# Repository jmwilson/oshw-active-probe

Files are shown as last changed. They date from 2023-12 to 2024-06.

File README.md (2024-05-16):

# Active probe project

Read about this project at https://jmw.name/projects/active-probe/

## Repository structure

* `board`: schematic and layout design files
	- `Mfg`: Gerbers and manufacturing outputs
* `measurement`: prototype performance measurements
* `simulation\openems`: openEMS simulation files
	- `probe`: input network simulation
	- `transmission-lines`: coplanar waveguide transmission line simulation
* `simulation\spice`: circuit simulations

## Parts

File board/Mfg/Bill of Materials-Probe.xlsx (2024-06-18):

Comment | Description | Designator | Footprint | LibRef | Quantity | Manufacturer | Manufacturer Part Number | Manufacturer 1 | Manufacturer 2 | Manufacturer 3 | Manufacturer 4 | Manufacturer Part Number 1 | Manufacturer Part Number 2 | Manufacturer Part Number 3 | Manufacturer Part Number 4 | Supplier Part Number 1
4.70K | RES 4.70K OHM 1% 1/10W 0603 | R24 | RESC0603(1608)_M | RESC0603-4K70-1pct | 1 | Yageo | RC0603FR-074K7L | Yageo | Stackpole Electronics | Vishay Dale | Panasonic Electronic Components | RC0603FR-074K7L | RMCF0603FT4K70 | CRCW06034K70FKEA | ERJ-3EKF4701V
422K | RES 422K OHM 1% 1/16W 0402 | R4 | RESC0402(1005)_M | RESC0402-422K-1pct | 1 | Yageo | RC0402FR-07422KL | Yageo | Stackpole Electronics | Vishay Dale | Panasonic Electronic Components | RC0402FR-07422KL | RMCF0402FT422K | CRCW0402422KFKED | ERJ-2RKF4223X
100 | RES 100 OHM 1% 1/16W 0402 | R1 | RESC0402(1005)_M | RESC0402-100R-1pct | 1 | Yageo | RC0402FR-07100RL | Yageo | Stackpole Electronics | Vishay Dale | Panasonic Electronic Components | RC0402FR-07100RL | RMCF0402FT100R | CRCW0402100RFKED | ERJ-2RKF1000X
91.0K | RES 91.0K OHM 1% 1/16W 0402 | R21 | RESC0402(1005)_M | RESC0402-91K0-1pct | 1 | Yageo | RC0402FR-0791KL | Yageo | Stackpole Electronics | Vishay Dale | Panasonic Electronic Components | RC0402FR-0791KL | RMCF0402FT91K0 | CRCW040291K0FKED | ERJ-2RKF9102X
68 | RES 68 OHM 1% 1/16W 0402 | R9 | RESC0402(1005)_M | RESC0402-68R0-1pct | 1 | Yageo | RC0402FR-0768RL | Yageo | Stackpole Electronics | Vishay Dale | Panasonic Electronic Components | RC0402FR-0768RL | RMCF0402FT68R0 | CRCW040268R0FKED | ERJ-2RKF68R0X
66.5K | RES 66.5K OHM 1% 1/16W 0402 | R8 | RESC0402(1005)_M | RESC0402-66K5-1pct | 1 | Yageo | RC0402FR-0766K5L | Yageo | Stackpole Electronics | Vishay Dale | Panasonic Electronic Components | RC0402FR-0766K5L | RMCF0402FT66K5 | CRCW040266K5FKED | ERJ-2RKF6652X
51.0K | RES 51.0K OHM 1% 1/16W 0402 | R11 | RESC0402(1005)_M | RESC0402-51K0-1pct | 1 | Yageo | RC0402FR-0751KL | Yageo | Stackpole Electronics | Vishay Dale | Panasonic Electronic Components | RC0402FR-0751KL | RMCF0402FT51K0 | CRCW040251K0FKED | ERJ-2RKF5102X
49.9 | RES 49.9 OHM 1% 1/16W 0402 | R19 | RESC0402(1005)_M | RESC0402-49R9-1pct | 1 | Yageo | RC0402FR-0749R9L | Yageo | Stackpole Electronics | Vishay Dale | Panasonic Electronic Components | RC0402FR-0749R9L | RMCF0402FT49R9 | CRCW040249R9FKED | ERJ-2RKF49R9X
41.2K | RES 41.2K OHM 1% 1/16W 0402 | R20 | RESC0402(1005)_M | RESC0402-41K2-1pct | 1 | Yageo | RC0402FR-0741K2L | Yageo | Stackpole Electronics | Vishay Dale | Panasonic Electronic Components | RC0402FR-0741K2L | RMCF0402FT41K2 | CRCW040241K2FKED | ERJ-2RKF4122X
18.0K | RES 18.0K OHM 1% 1/16W 0402 | R23 | RESC0402(1005)_M | RESC0402-18K0-1pct | 1 | Yageo | RC0402FR-0718KL | Yageo | Stackpole Electronics | Vishay Dale | Panasonic Electronic Components | RC0402FR-0718KL | RMCF0402FT18K0 | CRCW040218K0FKED | ERJ-2RKF1802X
17.8K | RES 17.8K OHM 1% 1/16W 0402 | R16 | RESC0402(1005)_M | RESC0402-17K8-1pct | 1 | Yageo | RC0402FR-0717K8L | Yageo | Stackpole Electronics | Vishay Dale | Panasonic Electronic Components | RC0402FR-0717K8L | RMCF0402FT17K8 | CRCW040217K8FKED | ERJ-2RKF1782X
10.0M | RES 10.0M OHM 1% 1/16W 0402 | R10 | RESC0402(1005)_M | RESC0402-10M0-1pct | 1 | Yageo | RC0402FR-0710ML | Yageo | Stackpole Electronics | Vishay Dale | Panasonic Electronic Components | RC0402FR-0710ML | RMCF0402FT10M0 | CRCW040210M0FKED
10.0K | RES 10.0K OHM 1% 1/16W 0402 | R12 | RESC0402(1005)_M | RESC0402-10K0-1pct | 1 | Yageo | RC0402FR-0710KL | Yageo | Stackpole Electronics | Vishay Dale | Panasonic Electronic Components | RC0402FR-0710KL | RMCF0402FT10K0 | CRCW040210K0FKED | ERJ-2RKF1002X
10.2K | RES 10.2K OHM 1% 1/16W 0402 | R22 | RESC0402(1005)_M | RESC0402-10K2-1pct | 1 | Yageo | RC0402FR-0710K2L | Yageo | Stackpole Electronics | Vishay Dale | Panasonic Electronic Components | RC0402FR-0710K2L | RMCF0402FT10K2 | CRCW040210K2FKED | ERJ-2RKF1022X
5.60K | RES 5.60K OHM 1% 1/16W 0402 | R15 | RESC0402(1005)_M | RESC0402-5K60-1pct | 1 | Yageo | RC0402FR-075K6L | Yageo | Stackpole Electronics | Vishay Dale | Panasonic Electronic Components | RC0402FR-075K6L | RMCF0402FT5K60 | CRCW04025K60FKED | ERJ-2RKF5601X
0 | RES 0 OHM JUMPER 0402 | R2 | RESC0402(1005)_M | R0402-0R0-JMP | 1 | Yageo | RC0402FR-071RL | Yageo | Stackpole Electronics | Vishay Dale | Panasonic Electronic Components | RC0402FR-071RL | RMCF0402FT1R00 | CRCW04021R00FNED | ERJ-2GE0R00X
1.91M | RES 1.91M OHM 1% 1/16W 0402 | R6 | RESC0402(1005)_M | RESC0402-1M91-1pct | 1 | Yageo | RC0402FR-071M91L | Yageo | Stackpole Electronics | Vishay Dale | Panasonic Electronic Components | RC0402FR-071M91L | RMCF0402FT1M91 | CRCW04021M91FKED
1.60M | RES 1.60M OHM 1% 1/16W 0402 | R3 | RESC0402(1005)_M | RESC0402-1M60-1pct | 1 | Yageo | RC0402FR-071M6L | Yageo | Stackpole Electronics | Vishay Dale | Panasonic Electronic Components | RC0402FR-071M6L | RMCF0402FT1M60 | CRCW04021M60FKED
1.00K | RES 1.00K OHM 1% 1/16W 0402 | R17, R18 | RESC0402(1005)_M | RESC0402-1K00-1pct | 2 | Yageo | RC0402FR-071KL | Yageo | Stackpole Electronics | Vishay Dale | Panasonic Electronic Components | RC0402FR-071KL | RMCF0402FT1K00 | CRCW04021K00FKED | ERJ-2RKF1001X
1k | TRIMMER 1K OHM 0.25W J LEAD TOP | R13 | PVG3A | PVG3A102C01R00 | 1 | Bourns | PVG3A102C01R00 |  |  |  |  |  |  |  |  | 490-2643-6-ND
1u | Cap Ceramic 1uF 50V X7R 10% SMD 0805 125C Blister T/R | C7 | CAPC0805(2012)145_M | CC0805KKX7R9BB105 | 1 | Yageo | CC0805KKX7R9BB105 |  |  |  |  |  |  |  |  | 311-1886-1-ND
1.1p | CAP CER 1.1PF±0.05PF 50V C0G/NP0 0402 | C4 | CAPC0402(1005)50_M | GJM1555C1H1R1WB01 | 1 | Murata | GJM1555C1H1R1WB01D
1.3p | CAP CER 1.3PF±0.05PF 50V C0G/NP0 0402 | C5 | CAPC0402(1005)50_M | GJM1555C1H1R3WB01 | 1 | Murata | GJM1555C1H1R3WB01D
2.1/5.5mm | CONN PWR JACK 2X5.5MM SOLDER | J4 | CUI PJ-002A | PJ-002A | 1 | CUI | PJ-002A |  |  |  |  |  |  |  |  | CP-002A-ND
4.7u | CAP CER 4.7UF 50V X7R 0805 | C22, C23, C24, C25 | CAPC0805(2012)100_M | GRM21BZ71H475KE15K | 4 | Murata | GRM21BZ71H475KE15K |  |  |  |  |  |  |  |  | 490-GRM21BZ71H475KE15KCT-ND
10n | CAP CER 10NF±5% 25V C0G 0402, CAP CER 10NF±10% 50V X7R 0402 | C6, C8, C9, C18, C19, C20, C21 | CAPC0402(1005)50_M | GRM1555C1E103JE01, GRM155R71H103KA88 | 7 | Murata | GRM1555C1E103JE01D, GRM155R71H103KA88D
22u | CAP TANT 22UF 10% 16V 1411 | C10, C11 | KEMET B_M | T491B226K016AT | 2 | KEMET | T491B226K016AT |  |  |  |  |  |  |  |  | 399-8312-6-ND
47p | CAP CER 47PF±5% 50V C0G 0402 | C2 | CAPC0402(1005)50_M | CL05C470JB5NNN | 1 | Samsung Electro-Mechanics | CL05C470JB5NNNC
100n | CAPACITOR CERAMIC, 0.1UF, 50V, X7R, 10%, 0603 | C12, C13 | CAPC0603(1608)100_M | CC0603KRX7R9BB104 | 2 | Yageo | CC0603KRX7R9BB104 |  |  |  |  |  |  |  |  | 311-1344-1-ND
100n LICC | CAP CER 0.1UF 25V X7R 0306 | C14, C15, C16, C17 | CAPC0306_M | TWK107B7104MVHT | 4 | Taiyo Yuden | TWK107B7104MVHT |  |  |  |  |  |  |  |  | 587-6181-1-ND
100p | CAP CER 100PF±5% 50V C0G 0402 | C3 | CAPC0402(1005)50_M | CL05C101JB5NNN | 1 | Samsung Electro-Mechanics | CL05C101JB5NNNC
330p | CAP CER 330PF±5% 50V C0G 0402 | C1 | CAPC0402(1005)50_M | GRM1555C1H331JA01 | 1 | Murata | GRM1555C1H331JA01D
0339-0-15-01-15-27-10-0 | CONN PIN RCPT | J1, J2, J5 | MILL-MAX 0339 | 0339-0-15-01-15-27-10-0 | 3 | Mill-Max | 0339-0-15-01-15-27-10-0 |  |  |  |  |  |  |  |  | 0339-0-15-01-15-27-10-0-ND
901-10511-3 | CONN SMA JACK STR 50OHM EDGE MNT | J3 | 901-10511-3 | 901-10511-3 | 1 | Amphenol RF | 901-10511-3 |  |  |  |  |  |  |  |  | ARF2500-ND
BAT54 | DIODE SCHOTTKY 30V 200MA TO236AB | D1 | INF-PG-SC59_M | BAT54 | 1 | Nexperia USA | BAT54,215 |  |  |  |  |  |  |  |  | 1727-2900-6-ND
BUF802 | WIDE-BANDWIDTH JFET BUFFER | U1 | VQFN16_RGT_TEX- OSHPARK | BUF802IRGTR | 1 | Texas Instruments | BUF802IRGTR |  |  |  |  |  |  |  |  | 296-BUF802IRGTRCT-ND
LTC3261 | IC REG CHARG PUMP INV 12MSOP | U4 | MSOP-12_MSE | LTC3261EMSE | 1 | Analog Devices / Linear Technology | LTC3261EMSE#TRPBF |  |  |  |  |  |  |  |  | LTC3261EMSE#TRPBFCT-ND
OPA140 | IC OPAMP JFET 1 CIRCUIT 8SOIC | U2 | SOIC-8 | OPA140AIDR | 1 | Texas Instruments | OPA140AIDR |  |  |  |  |  |  |  |  | 296-43606-6-ND
TPS7A39 | IC REG LINEAR POS/NEG ADJ 10WSON | U3 | DSC0010J_NV | TPS7A3901DSCR | 1 | Texas Instruments | TPS7A3901DSCR |  |  |  |  |  |  |  |  | 296-TPS7A3901DSCRCT-ND
VLMTG1300-GS08 | LED GREEN 0603 SMD | D2 | LED0603(1608)_M | VLMTG1300-GS08 | 1 | Vishay Semiconductors | VLMTG1300-GS08 |  |  |  |  |  |  |  |  | VLMTG1300-GS08CT-ND

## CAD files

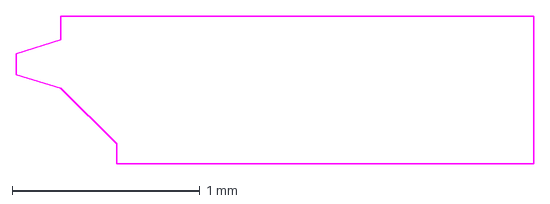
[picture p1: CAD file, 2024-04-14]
board/Probe-outline.DXF
2.76 x 0.787 mm

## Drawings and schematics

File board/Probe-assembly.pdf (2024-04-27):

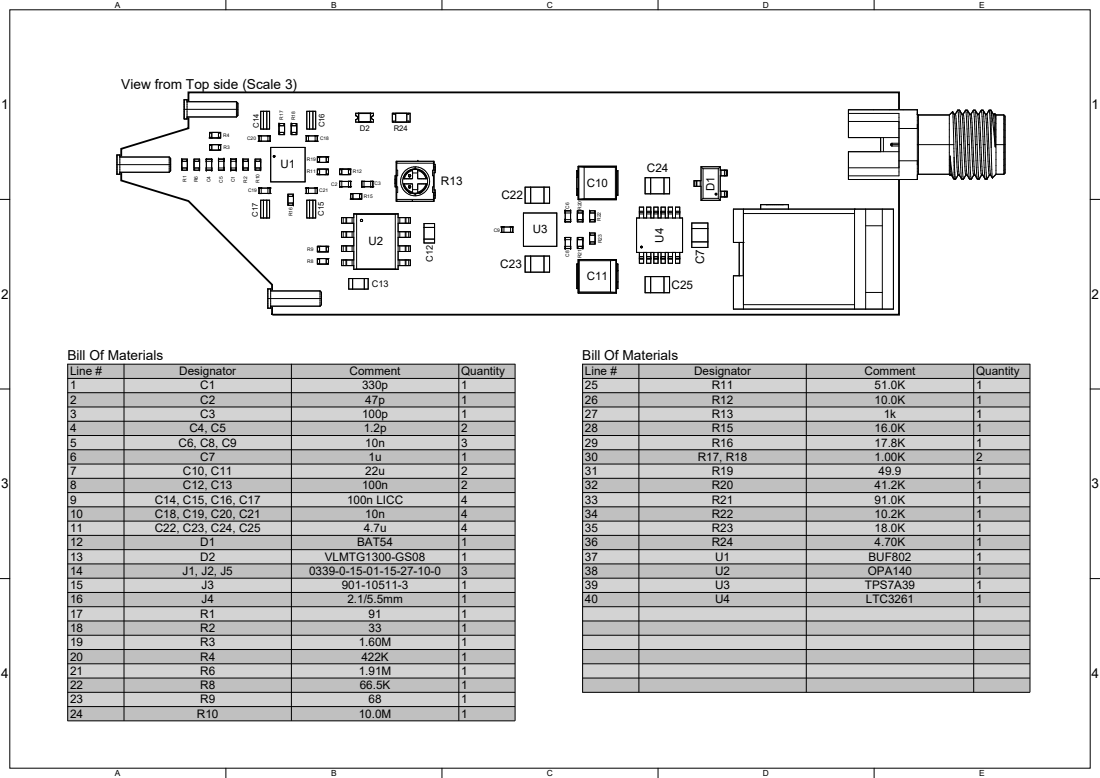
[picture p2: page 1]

View from Top side (Scale 3)

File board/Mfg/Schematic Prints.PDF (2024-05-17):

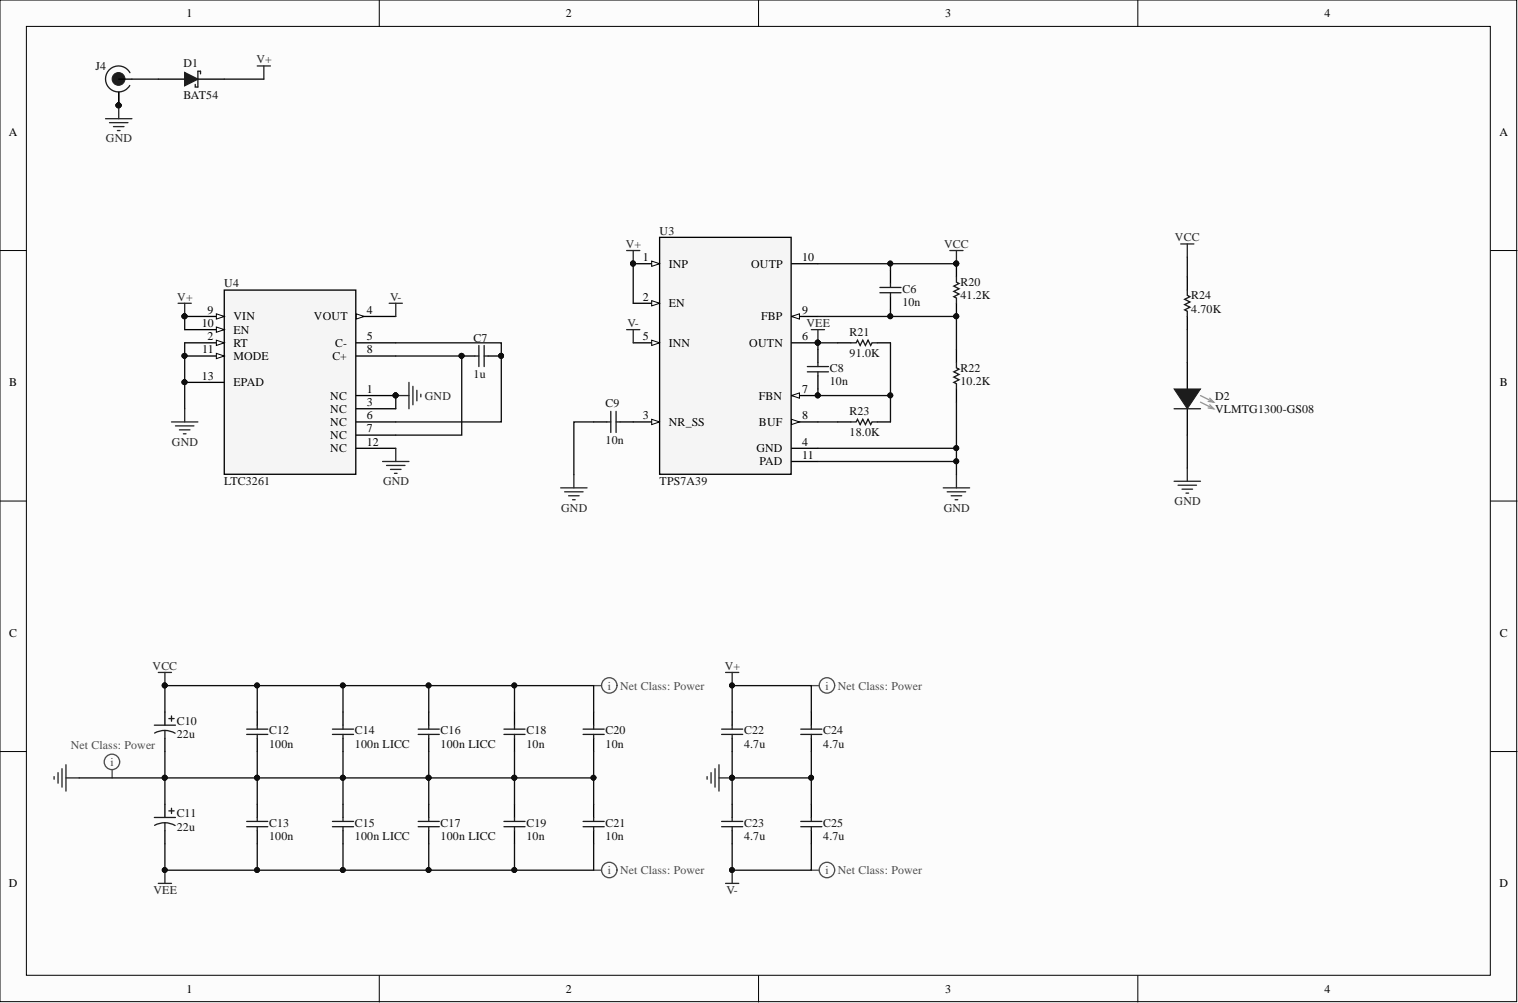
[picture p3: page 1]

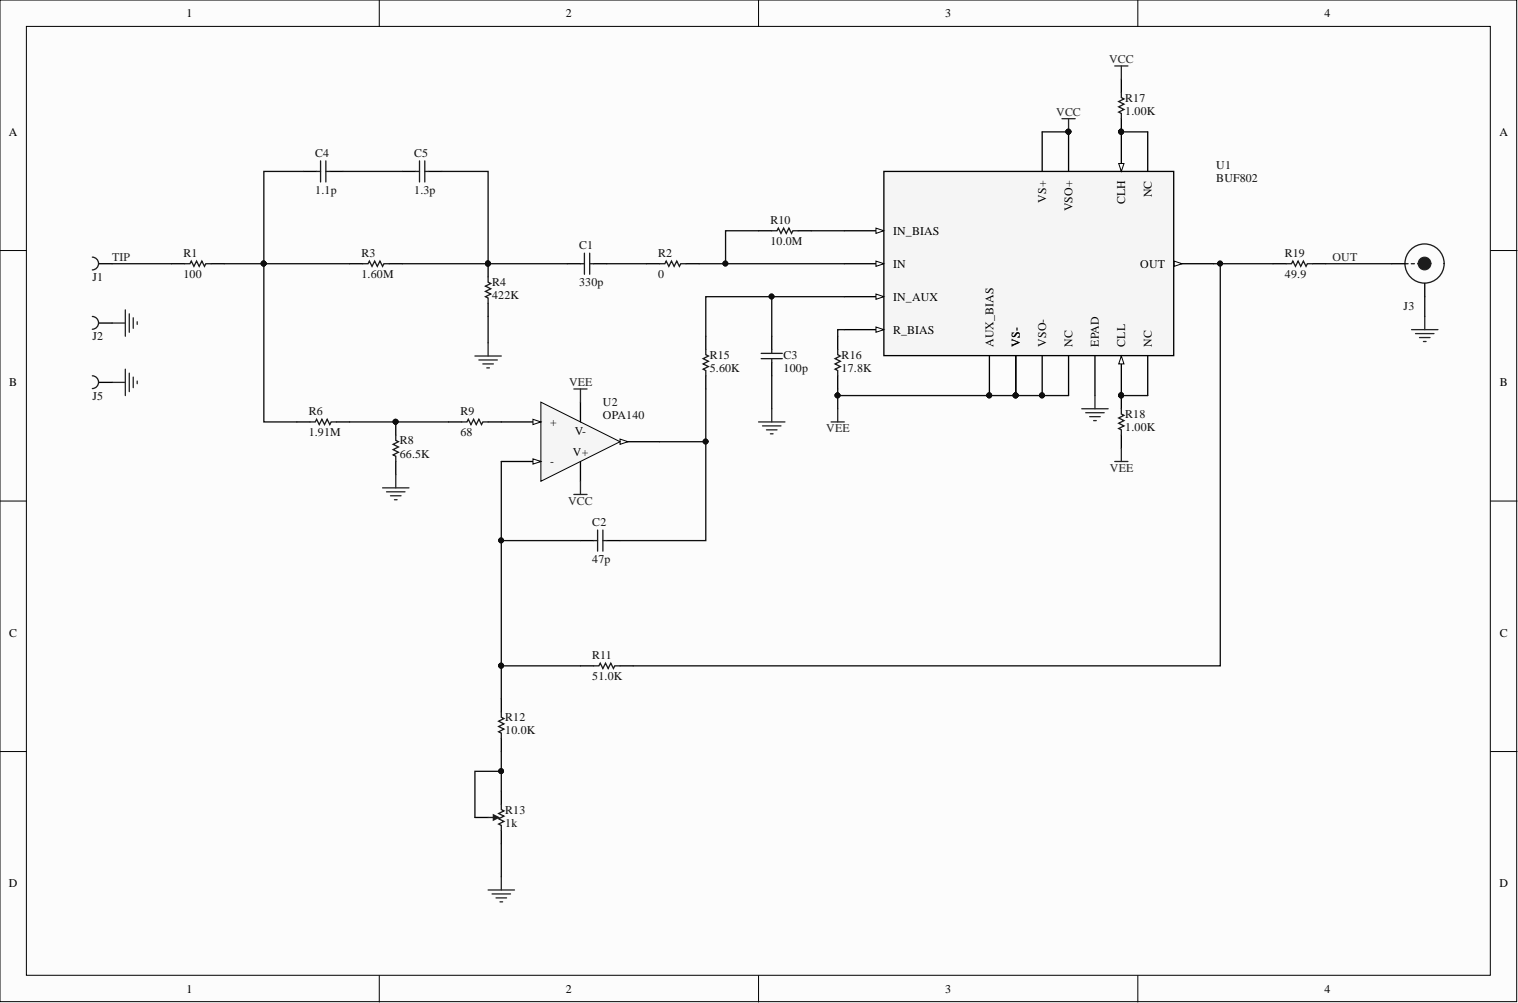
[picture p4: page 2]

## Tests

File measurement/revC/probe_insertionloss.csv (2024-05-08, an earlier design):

Frequency [Hz] | Magnitude [dB]
100000000 | -20.0424499511719
114500000 | -20.0411605834961
129000000 | -20.0714073181152
143500000 | -20.0852661132813
158000000 | -19.9981155395508
172500000 | -20.0230140686035
187000000 | -20.0642738342285
201500000 | -20.017261505127
216000000 | -20.0806884765625
230500000 | -20.0726261138916
245000000 | -19.9825057983398
259500000 | -20.0185470581055
274000000 | -20.0681571960449
288500000 | -20.0335426330566
303000000 | -20.0731315612793
317500000 | -20.0553703308105
332000000 | -20.0141181945801
346500000 | -20.0350360870361
361000000 | -20.053295135498
375500000 | -20.0479755401611
390000000 | -20.0690574645996
404500000 | -20.0616073608398
419000000 | -20.0312309265137
433500000 | -20.0324001312256
448000000 | -20.0445594787598
462500000 | -20.0611763000488
477000000 | -20.0432395935059
491500000 | -19.9985198974609
506000000 | -19.9425964355469
520500000 | -19.943302154541
535000000 | -19.9910869598389
549500000 | -20.007152557373
564000000 | -19.9807739257813
578500000 | -19.9123687744141
593000000 | -19.8353004455566
607500000 | -19.8540916442871
622000000 | -19.9032077789307
636500000 | -19.9113254547119
651000000 | -19.8602237701416
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

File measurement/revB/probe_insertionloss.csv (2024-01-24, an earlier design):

Name | Sweep (T1)
Date | 2024-02-06
Time | 10:57:33
Instrument | FPC1500 - 103124/003
Firmware Version | V1.80
Country of Origin | Czech Republic
Instrument Mode | Spectrum Analyzer
Meas Mode | Spectrum
Uplink | - - -
Downlink | - - -
Channel | - - -
Center Frequency | 1550000000 | Hz
Frequency Offset | 0 | Hz
Span | 2900000000 | Hz
Ref Level | -33 | dBm
Ref Offset | 0 | dB
Ref Position | 0.90
Range | 30 | dB
RF Attenuation | Auto Low Distortion
RF Attenuator | 10 | dB
Pre-Amplifier | On
RF Input | 50 Ω
RBW | 3000000 | Hz
VBW | 3000000 | Hz
SWT | 0.037 | s
Trigger Mode | Free Run
Trigger Level | - - -
Trigger Delay | - - -
Trace Mode | Average
Trace Math | Off
Trace Detector | Sample
Primary Transducer | - - -
Secondary Transducer | - - -
Isotropic Antenna | Off
Generator Mode | TG
TG Frequency Offset | 0 | Hz
TG Level | -20 | dBm
Normalization S21 | On
Average Count | Sweep 10 of 10
Limit Line 1 | - - -
Result Limit Line 1 | - - -
Limit Line 2 | - - -
Result Limit Line 2 | - - -
Marker 1 | 2000000000 | Hz
Marker 1 Value | -22.21 | dB
Frequency [Hz] | Magnitude [dB]
100000000 | -20.2905426025391
102453468.697124 | -20.2877464294434
104906937.394247 | -20.2849617004395
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

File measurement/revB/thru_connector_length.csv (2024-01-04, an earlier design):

Name | Sweep
Date | 2024-01-03
Time | 15:13:24
Instrument | FPC1500 - 103124/003
Firmware Version | V1.80
Country of Origin | Czech Republic
Instrument Mode | Vector Network Analyzer
Meas Mode | Return Loss
Bridge Mode | S11
Format | Phase
Calibration State | Calibrated Interpolated
Suppression | Off
Aperture Steps | 1
Uplink | - - -
Downlink | - - -
Phase Unwrap | On
Center Frequency | 1352523957 | Hz
Frequency Offset | 0 | Hz
Span | 2701047914 | Hz
Start Frequency | 2000000 | Hz
Stop Frequency | 2703047914 | Hz
Ref Level | 0 | °
Range | 180 | °
Trigger Mode | Free Run
Trigger Delay | - - -
Trace Mode | Clear / Write
Trace Detector | Sample
Frequency | 0 | Hz
Number of Points | 501
Loss | 0 | dB/m
Electrical Length | 0.014839 | m
Limit Line 1 | - - -
Result Limit Line 1 | - - -
Limit Line 2 | - - -
Result Limit Line 2 | - - -
Frequency [Hz] | Magnitude [dB] | Phase [°]
2000000 | 0.0470551811158657 | 179.670181274414
7402095.828 | 0.0343912243843079 | 179.827713012695
12804191.656 | 0.0491640418767929 | 179.581756591797
18206287.484 | 0.0227663572877645 | 179.364013671875
23608383.312 | 0.0407255105674267 | 179.150863647461
29010479.14 | 0.0158897954970598 | 178.852279663086
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

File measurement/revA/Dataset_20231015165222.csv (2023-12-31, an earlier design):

Name | Sweep (T1)
Date | 2023-10-15
Time | 15:51:07
Instrument | FPC1500 - 103124/003
Firmware Version | V1.80
Country of Origin | Czech Republic
Instrument Mode | Spectrum Analyzer
Meas Mode | Spectrum
Uplink | - - -
Downlink | - - -
Channel | - - -
Center Frequency | 1550000000 | Hz
Frequency Offset | 0 | Hz
Span | 2900000000 | Hz
Ref Level | -20 | dBm
Ref Offset | 0 | dB
Ref Position | 1.00
Range | 30 | dB
RF Attenuation | Auto Low Distortion
RF Attenuator | 0 | dB
Pre-Amplifier | Off
RF Input | 50 Ω
RBW | 3000000 | Hz
VBW | 3000000 | Hz
SWT | 0.037 | s
Trigger Mode | Free Run
Trigger Level | - - -
Trigger Delay | - - -
Trace Mode | Clear / Write
Trace Math | Off
Trace Detector | Sample
Primary Transducer | - - -
Secondary Transducer | - - -
Isotropic Antenna | Off
Generator Mode | TG
TG Frequency Offset | 0 | Hz
TG Level | -20 | dBm
Normalization S21 | On
Limit Line 1 | - - -
Result Limit Line 1 | - - -
Limit Line 2 | - - -
Result Limit Line 2 | - - -
Frequency [Hz] | Magnitude [dB]
100000000 | -20.0037021636963
102453468.697124 | -19.9785385131836
104906937.394247 | -19.9533748626709
107360406.091371 | -19.9282112121582
109813874.788494 | -19.9030475616455
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

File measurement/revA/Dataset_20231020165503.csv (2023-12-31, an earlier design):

Name | Sweep (T1)
Date | 2023-10-20
Time | 15:53:41
Instrument | FPC1500 - 103124/003
Firmware Version | V1.80
Country of Origin | Czech Republic
Instrument Mode | Spectrum Analyzer
Meas Mode | Spectrum
Uplink | - - -
Downlink | - - -
Channel | - - -
Center Frequency | 1550000000 | Hz
Frequency Offset | 0 | Hz
Span | 2900000000 | Hz
Ref Level | -21.2 | dBm
Ref Offset | 0 | dB
Ref Position | 1.00
Range | 30 | dB
RF Attenuation | Auto Low Distortion
RF Attenuator | 0 | dB
Pre-Amplifier | Off
RF Input | 50 Ω
RBW | 3000000 | Hz
VBW | 3000000 | Hz
SWT | 0.037 | s
Trigger Mode | Free Run
Trigger Level | - - -
Trigger Delay | - - -
Trace Mode | Clear / Write
Trace Math | Off
Trace Detector | Sample
Primary Transducer | - - -
Secondary Transducer | - - -
Isotropic Antenna | Off
Generator Mode | TG
TG Frequency Offset | 0 | Hz
TG Level | -20 | dBm
Normalization S21 | On
Limit Line 1 | - - -
Result Limit Line 1 | - - -
Limit Line 2 | - - -
Result Limit Line 2 | - - -
Frequency [Hz] | Magnitude [dB]
100000000 | -19.900577545166
102453468.697124 | -19.8989448547363
104906937.394247 | -19.8973121643066
107360406.091371 | -19.8956775665283
109813874.788494 | -19.8940448760986
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

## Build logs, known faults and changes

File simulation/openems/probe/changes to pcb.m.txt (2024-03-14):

Fix board outline:
pgon = [];
pgon(:, end+1) = [0.00605;0.02];
pgon(:, end+1) = [0.00605;0.016775];
pgon(:, end+1) = [0;0.014923];
pgon(:, end+1) = [0;0.012077];
pgon(:, end+1) = [0.00605;0.010225];
pgon(:, end+1) = [0.013575;0.0027];
pgon(:, end+1) = [0.013575;0];
pgon(:, end+1) = [0.07445;0];
pgon(:, end+1) = [0.07445;0.02];

octave --no-gui preview.m
octave --no-gui probe_input.m
s2spice.exe /l /s /q /f parameters.s4p

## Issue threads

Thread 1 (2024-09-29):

Enclosures can hide copyright info

Johnsel, 2024-09-29:
Hi,

I've tried to reach out a few times. I assume you're not interesed in talking. I will point out here that a fully enclosing encslosure would hide copyright information. I'm not sure what you want in thsi case. Do you want something on the enclosure?

John

jmwilson, 2024-10-01:
Hi John, I'm not sure where you reached out, but my apologies if I've been unresponsive. The probe design files are licensed under CERN-OHL-S-2.0, which require the design files to accompany (or a link provided to the design source) a manufactured product or derived work. I do not believe it specifically requires the product to be marked with copyright information - see sections 3.3 and 4 of the license file.

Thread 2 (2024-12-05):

Improving Manufacturability/Reducing Unique BOM items

sethkaz, 2024-12-05:
First of all, thanks for doing the hard work, the testing to prove it, and sharing the results!

I'm planning on building this project, and after reviewing the BOM I was wondering if you could explain why certain component choices were made?

From my understanding, you could make the following changes and not affect the operation of the probe:
R22: 10.2k -> 10.0k
R20: 41.2k -> 40.2k (or arguably don't change)
R23: 18.0k -> 17.8k (or even 10.0k)
R21: 91.0k -> 88.7k (or 50.5k if you're using R23=10k)
R24: 4.7k -> 5.6k (or 1.00k if you want the LED much brighter)

Thanks!

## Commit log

2023-07-19 Initial test
    [Power.SchDoc, Probe-input.PcbDoc, Probe.PcbDoc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]
2023-07-21 Second run
    [Probe-input.PcbDoc, Probe.PcbDoc, Probe.PrjPCB]
2023-07-22 Run #3: .96 pF / 18 nH
    [Probe-input.PcbDoc, Probe.PcbDoc, Probe.SchDoc]
2023-07-23 Run #4: unchanged C_in, slightly overdamped
    [Probe-input.PcbDoc, Probe.PcbDoc, Probe.PrjPCB]
2023-07-23 Run #5: unchanged C_in, properly damped
    [Probe-input.PcbDoc, Probe.PcbDoc]
2023-07-24 Run #6: .89 pF / 8 nH
    [Probe-input.PcbDoc, Probe.PcbDoc]
2023-07-26 Run #8: redo of #7 with 68R series resistor. Better: .89 pF / 10 nH / 1.9 GHz
    [Probe-input.PcbDoc, Probe.PcbDoc, Probe.SchDoc]
2023-07-27 Run #9: change C6 to 0.8p, move R1 up to the input pin, tried adding loss to FR-4 but seems inconsequential. Results: .83 pF / 11 nH / 1.97 GHz
2023-07-31 Run 10: fixed spurious spikes in simulation, .91 pF / 10 nH / 1.93 GHz
    [Probe-input.PcbDoc, Probe.PcbDoc, Probe.SchDoc]
2023-08-20 0201 components, first draft
    [Probe-input.PcbDoc, Probe.PcbDoc, Probe.PrjPCB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]
2023-08-23 0201 version, run #15: .9 pF / 13 nH / 1.9 GHz
    [Probe-input.PcbDoc, Probe.PcbDoc, Probe.PrjPCB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]
2023-09-01 Return to 0402s, use inner plane capacitor instead of trimmer, draft, 1.2 pF / 1.6 GHz
2023-09-19 Run #16: 1 pF / 2.0 GHz
    [Probe-input.PcbDoc, Probe.PcbDoc, Probe.PrjPCB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]
2023-09-28 Run #17: 1 pF / 2 GHz, pull from prototype layout
2023-09-28 Proto 1 to OSHPark
    [Power.SchDoc, Probe-input.PcbDoc, Probe.PcbDoc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]
2023-11-21 Measurements of proto 1
    [Dataset_20231015165222.csv, Dataset_20231020165503.csv, Dataset_20231117143316.csv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]
2023-11-21 Proto 2
    [Bill of Materials-Probe.xlsx, Power.SchDoc, Probe-input.PcbDoc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]
2023-12-31 Reorganize directory structure for sharing
    [Bill of Materials-Probe.xlsx, Dataset_20231015165222.csv, Dataset_20231020165503.csv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]
2024-01-04 Add port extension in probe impedance calculation
    [thru_connector_length.csv]
2024-01-15 Lossy material simulation
2024-01-24 Update S21 measurement after tuning for crossover flatness
    [probe_insertionloss.csv]
2024-01-29 Use PML boundary condition in simulation
    [Probe-input.PcbDoc]
2024-03-14 Simulation layout change to fixed capacitors
2024-04-05 Rev C layout with fixed frequency comp. capacitors, trimpot for LF gain, PDN tweaks
    [Bill of Materials-Probe.xlsx, Power.SchDoc, Probe-input.PcbDoc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]
2024-04-14 Rev C stencil jig
    [Probe-outline.DXF]
2024-04-27 Rev C assembly diagram
    [Probe.PrjPCB]
2024-05-08 Add measurements for rev C
    [probe_insertionloss.csv]
2024-05-12 Tune passive values from measurement/sim
    [Probe.PcbDoc, Probe.SchDoc]
2024-05-16 Rename revisions for consistency
    [Dataset_20231015165222.csv, Dataset_20231020165503.csv, Dataset_20231117143316.csv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]
2024-05-17 Update schematic PDF
2024-06-18 Update with BOM xlsx and P&P csv
    [Bill of Materials-Probe.xlsx, Pick Place for Probe.csv]
